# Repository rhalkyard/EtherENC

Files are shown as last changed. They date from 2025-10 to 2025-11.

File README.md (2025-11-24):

# ENC624J600-based Ethernet card for Acorn Archimedes and Risc PC systems

From the same person who still hasn't quite finished
[SEthernet](https://github.com/rhalkyard/SEthernet), comes yet another Ethernet
card for vintage computers!

Ethernet cards for Acorn systems are even harder to find than for vintage Macs.
This project is an attempt to bring a modern, low-cost Ethernet card to Acorn
Archimedes and Risc PC machines.

## Project Status

Early days yet! I have the driver functioning on a prototype version of the
card, but there are enough issues that it'll need a redone board before I'm
truly happy with it.

Meanwhile, someone else in the Acorn community who has access to a lot more
hardware for testing, has [announced his own open-source Ethernet
podule](https://www.stardot.org.uk/forums/viewtopic.php?p=468283). To be
brutally honest, his design is probably the sensible path forward, and there
probably isn't room for two very similar projects in such a small community, so
this project's future is in question. However, I'm proud of what I accomplished,
my design works well (in my opinion), and I think it's worth saving for
posterity, so here it is.

## Supported Systems

The intent is for this card to be compatible with any RISC OS machine with 16-
or 8-bit Podule slots, running RISC OS 3.10 or later. However, I only have
access to an A3000, so testing on later OSes and other machines will be up to
others!

## Hardware

See [HARDWARE.md](HARDWARE.md) for a design overview.

Schematic in PDF format can be found at
[pcb/EtherENC-prototype/EtherENC-Prototype.pdf](pcb/EtherENC-prototype/EtherENC-Prototype.pdf).

## Software

The [EtherENC/](EtherENC) directory contains driver source, buildable with Acorn
C/C++ version 5, which can be obtained from
[https://www.4corn.co.uk/articles/acornc5/](https://www.4corn.co.uk/articles/acornc5/),
or included in [RPCEMU](https://www.marutan.net/rpcemu/index.php)'s RISC OS 3.71
Easy-Start bundle.

If you are not used to RISC OS, the filenames and layout will look a little
weird. Instead of having extensions, `.c` and `.h` files live in separate
directories, and the comma-suffixes on various file names encode RISC OS file
types. Of particular interest, the `,ffb` files are BBC Basic programs, however
these are stored in a binary format and their source is not easily viewable on
non-RISC OS systems. Accompanying text dumps of the program code are included
alongside, I will endeavour to keep these up to date.

`MkROM` is a BASIC program that builds the card's ROM image with the appropriate
headers and loadable driver module.

`WriteROM` can then be used to program or update the card's flash with the new
ROM image.

### Checkout

Note that this repository includes the [RISC OS Open TCPIPLibs
source](https://gitlab.riscosopen.org/RiscOS/Sources/Lib/TCPIPLibs) as a
submodule. Specifically, it uses the
[TCPIPLibs-5_01](https://gitlab.riscosopen.org/RiscOS/Sources/Lib/TCPIPLibs/-/tree/TCPIPLibs-5_01)
tag, as this corresponds to the DCI 4.04 specification, without bringing in a
bunch of changes that make old versions of Acorn C/C++ get confused.

After cloning this repo, run `git submodule update --init` to set up submodules
correctly.

### Building

1. Install Acorn C/C++ and run `!SetPaths` inside the Acorn C/C++ directory.

2. Run the `!Mk` script in the source directory (or run `amu` from a TaskWindow
   or CLI).

### Flashing

1. After building the EtherENC driver, run `WriteROM` and follow the prompts.

### Installation

These instructions assume that you are using the version of `!Internet` included
in the Universal !Boot distribution. If you are using something else, you should
probably be able to figure out how to adapt them to your setup!

1. Copy `AutoSense.EtherENC` to
   `!Boot.Resources.Configure.!InetSetup.AutoSense`.

2. (optional) Copy the built `EtherENC` module to
   `!Boot.Resources.System.Modules.Network`. The driver module from the card ROM
   should be sufficient, but when testing it can be useful to softload the
   module instead.

3. Restart RISC OS.

### Configuring

Configuring the card is more or less the same as any other network interface on
RISC OS, and is done by the `!Boot.Resources.Configure.!InetSetup` application:

1. Run `!Boot.Resources.Configure.!InetSetup`, and click the `Internet` icon.

2. Under `Interfaces`, tick the box next to `EtherENC`, click the adjacent
   `Configure...` button, and set your IP address and netmask. Unless you know
   what you're doing, `Obtain IP address` should be set to `Manually`, and
   `Primary interface` should be ticked.

2. Under `Routing`, enter your default gateway. Unless you know what you're
   doing, `Act as an IP router` and `Run RouteD` should not be ticked.

3. Under `Host names`, ether your hostname domain, and DNS server(s). Ensure
   that `Use name servers also` is selected.

4. Configure AUN and Access if necessary (doing so is beyond the scope of this
   document).

#### CMOS Settings

The system's CMOS memory is used to store hardware configuration options across
reboots. These options can be set and read using RISC OS' `*Configure` and
`*Status` commands.

`*Configure EENCFlow <unit> Off|On` - Enable or disable PAUSE-frame flow
control, which may help mitigate packet drops on heavily-loaded systems. Default
is `Off`. Flow control can only operate on full-duplex links.

`*Configure EENCLink <unit> Auto | 10 Half|Full | 100 Half|Full` - Configure
link mode. `Auto` (the default) causes link speed and duplex mode to be
autonegotiated with the link partner. Otherwise, a fixed speed and duplex
setting (one of `10 Half`, `10 Full`, `100 Half` or `100 Full`) can be set.

After installing the card, or moving it into another slot, it may be necessary
to reconfigure the card in order to overwrite any leftover CMOS settings from
previous residents of that slot. Defaults can be restored with:

```
*Configure EENCLink <unit> Auto
*Configure EENCFlow <unit> Off
```

## Licenses

Hardware (everything in the `pcb` and `pld` directories) is licensed under the
CERN Open Hardware License Version 2 - Strongly Reciprocal.

The driver (everything in the `EtherENC` directory) is licensed under the GNU
Public License Version 3, with the following exceptions:

- `EtherENC.s.iocopy` contains code derived from the 
  ["Ether1" driver](https://gitlab.riscosopen.org/RiscOS/Sources/Networking/Ethernet/Ether1/) 
  as published by Risc OS Online Ltd., under the Apache License, version 2.0.

- `EtherENC.h.filter` and `EtherENC.c.filter` contain code derived from the
  ["EtherY" driver](https://gitlab.riscosopen.org/RiscOS/Sources/Networking/Ethernet/EtherY/)
  as published by RISC OS Online Ltd., under the BSD License.

- `EtherENC.h.syslog` and `EtherENC.s.syslog` are included unmodified from the
  SysLog freeware application (https://compton.nu/software/riscos/syslog).

## To Do

- Finalise hardware design

- Performance testing and driver optimisation

## Allocations

Names and IDs registered with ROOL (see
[https://www.riscosopen.org/content/allocate](https://www.riscosopen.org/content/allocate)
for info). If you fork EtherENC and make software-incompatible changes, please
request your own allocations, as these are registered to me personally. However,
if your EtherENC-derived hardware is fully compatible with the mainline EtherENC
driver, you are welcome to use the same Podule IDs.

| Allocation Type | Allocation | Source locations |
| --- | --- | --- |
| Ethernet Driver Suffix | `ENC` | Everywhere |
| SWI Base | &5A9C0 | [`cmhg.ModuleHdr`](cmhg/ModuleHdr) |
| Module Name | `EtherENC` | [`cmhg.ModuleHdr`](cmhg/ModuleHdr) |
| Commands | `EENCInfo`, `EENCTest`, `EENCFlow`, `EENCLink` | [`cmhg.ModuleHdr`](cmhg/ModuleHdr), [`c.module`](c/module) |
| Error Block | &822800 | [`h.errors`](h/errors), [`MkROM`](MkROM.bas) |
| Podule Manufacturer ID | &72 | [`h.if_enc`](h/if_enc), [`MkROM`](MkROM.bas) |
| Podule Type ID | &14E (16 bit), &14F (8 bit) | [`h.if_enc`](h/if_enc), [`MkROM`](MkROM.bas) |

## References

- [RISC OS 3 Programmer's Reference Manual](http://www.riscos.com/support/developers/prm/)

- [Acorn Enhanced Expansion Card
  Specification](https://www.chiark.greenend.org.uk/~theom/riscos/docs/expspec.pdf)

- [RISC OS DCI4 Reference Manuals](https://gerph.github.io/riscos-prm-dci4/)

- [Ether1 (AMD LANCE-based card) driver source](https://gitlab.riscosopen.org/RiscOS/Sources/Networking/Ethernet/Ether1)

- [EtherY (LAN91C111-based card) driver source](https://gitlab.riscosopen.org/RiscOS/Sources/Networking/Ethernet/EtherY/)

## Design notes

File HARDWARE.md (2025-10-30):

# EtherENC Hardware

The hardware design has not been finalised (though a working prototype exists).
The basic schematic has been laid out, but board designs are still a work in
progress. Hopefully this document and the schematic will aid in understanding
the method to my madness.

## Key Components

Ethernet Controller: [Microchip
ENC624J600](https://ww1.microchip.com/downloads/en/devicedoc/39935b.pdf)

Flash ROM: [Microchip
SST39SF010](https://ww1.microchip.com/downloads/en/DeviceDoc/20005022C.pdf)

Glue logic CPLD: [Atmel
ATF1502](https://ww1.microchip.com/downloads/en/DeviceDoc/Atmel-0995-CPLD-ATF1502AS(L)-Datasheet.pdf)

## DIY-ability

A major intent of this project is to be low-cost and DIY-assemblable by the
skilled amateur, without any expensive tools or exotic skills. This is
constrained somewhat by the fact that the ENC624J600 and ATF1502 are only
available in surface-mount packages, but nevertheless they can still be
hand-soldered with good-quality flux, desoldering braid, and some practice.

Since surface-mount components were going to be involved anyway, I have gone
ahead and made everything surface mount, but avoided any unreasonably-tiny
footprints - the passives are all 0603 or larger. The trickiest part is the
ENC624J600 (a TQFP-44 with 0.5mm pin pitch), but there is no easier alternative.

Programming the ATF1502 requires a JTAG interface of some sort, however these
can be had very cheaply, and most can be driven by the free OpenOCD suite. Once
the ATF1502 is programmed, the flash ROM can be programmed in-system from RISC
OS, and this repo includes a simple BASIC program to do this.

## Data Width

The basic hardware design is intended to support both 16-bit standard Podules,
and the 8-bit 'mini Podules' used in the A3000, A4000 and A3010, with only minor
changes (configuration strapping of the ENC624J600, and paging of the buffer
RAM). Software handling of the two cards will differ, and 8 bit support has not
been implemented or tested yet, but much of the driver logic should be
applicable to both.

## Memory Map

| Mode | Address range | Read/Write | Width | Description |
| --- | --- | --- | --- | --- |
| IOC Fast | `0000-1FFF` | R/W <sup>1</sup> | 8 | Paged access to flash ROM <sup>2</sup> |
| IOC Fast | `2000` (shadowed through `23FF`) | R | 8 | IRQ status register |
| IOC Fast | `2000` (shadowed through `23FF`) | W | 8 | Paging latch for ROM and buffer RAM |
| IOC Fast | `2400-37FF` | - | - | Unused <sup>3</sup> |
| IOC Fast | `3800-3FFF` | R/W | 8/16 <sup>4</sup> | ENC624J600 registers <sup>5</sup> |
| MEMC | `0000-3FFF` | R/W | 8/16 <sup>4</sup> | Paged access to ENC624J600 address space <sup>6</sup> |

**Note 1:** Flash ROM is not directly writeable, but can be erased and
re-written with 'magic' write sequences. See `WriteROM`'s BASIC source for an
example implementation.

**Note 2:** 64 pages of 2048 bytes for 16 bit cards, 32 pages for 8 bit cards.

**Note 3:** Unused space is intended to accommodate the future inclusion of an
IanS-style IDE interface.

**Note 4:** Configurable by strapping pins.

**Note 5:** 256 16-bit registers for 16 bit cards, or 512 8-bit registers for
8-bit cards.

**Note 6:** 4 pages of 4096 halfwords for 16-bit cards, or 4 pages of 4096 bytes
for 8-bit cards (covering only top half of ENC624J600 address space in 8-bit mode).

### IRQ Status Register

The ENC624J600 puts its main IRQ status bit in bit 15 of its status register. On
16-bit cards, this renders it inaccessible to RISC OS' Podule IRQ routines, as
they use `LDRB` to read the status register, and Podules do not allow arbitrary
byte access.

To work around this, an IRQ status register is implemented at address `0x2000`:

| Bit | Description |
| --- | --- |
| 0 | Card is asserting `/PIRQ` |
| 1-7 | Unimplemented, reserved |

### Paging Latch

Paging for both ROM and the ENC624J600's address space is controlled by a
write-only latch at `0x2000`. Paging of the ENC624J600 address space is
controlled through the `Podule_CallLoader` SWI so as to allow these two paging
functions to coexist in a single register.

Paging bits are mapped as follows:

| Bit | ROM | ENC624J600 <sup>1</sup> |
| --- | --- | --- |
| 0 | A11 | - |
| 1 | A12 | - |
| 2 | A13 | - |
| 3 | A14 | - |
| 4 | A15 | - |
| 5 | A16 | - |
| 6 | - | A12 |
| 7 | - | A13 |

**Note 1:** In 16-bit mode, the ENC624J600's address pins correspond to halfword
addresses, rather than byte addresses.

Note that for 8-bit cards, there are insufficient paging bits to access the
entirety of the ENC624J600's memory. Address line A14 (unused in 16 bit mode) is
tied high, restricting paged access to the top 16K of the ENC624J600's address
space. This effectively prevents direct paged access to buffer memory, requiring
use of the ENC624J600's indirection registers instead.

## Theory of Operation

The ENC624J600 has a 32KB address space, providing 24KB of onboard buffer SRAM,
and a register bank at the top of its address space. In 16-bit mode, this
address space is laid out as 16K 16-bit halfwords. In 8-bit mode, an additional
address line is used, and access is as 32K 8-bit bytes. Due to the limitaitons
of the Podule bus, individual byte addressing in 16-bit mode is *not* possible. 

A commodity RJ45 jack with integrated magnetics and LEDs is used to simplify the
design. ROM is provided by an SST39SF010 128kx8 flash memory, which can be
programmed in-system using an included BASIC utility. Control and timing logic
is all implemented within an ATF1502 CPLD. An 8-bit latch provides a write-only
paging register, controlling paging of both ROM and the ENC624J600's address
space.

The ENC624J600 can be addressed in two 'modes', goverened by an address buffer
under control of the ATF1502. When `ETH_/PAGE` is asserted, the full complement
of Podule address bits (`LA13`..`LA2`), plus two paging-latch bits
(`ETH_PG1`..`ETH_PG0`) cover the full address space of the ENC624J600 in 16 bit
mode <sup>1</sup>. This is used for MEMC mode accesses to the ENC624J600's
buffer RAM. When `ETH_/PAGE` is not asserted, the high bits of the ENC624J600's
address bus are undriven and pulled high, exposing only the register space. This
mode is used to expose just the ENC624J600's registers in IOC space at
`3800-38FF`.

The ENC624J600 is a 3.3V device, with 5V-tolerant I/O. Its 3.3V supply is
provided by an onboard LDO regulator. In future hardware revisions, a regulator
with an Enable input under control of the ATF1502. This will be used to work
around the ENC624J600's lack of a hardware reset pin, by power-on-resetting the
chip when the Podule `/RST` line is asserted.

All components are tolerant of 500ns 'fast' accesses (and all slower access
modes too). 250ns timing is used for MEMC-space accesses to the ENC624J600,
equivalent to a RAM 'N-cycle'. `LDM`/`STM` to ENC624J600 RAM through MEMC space
is supported, though timing remains at 250ns throughout, MEMC does not appear to
support S-cycles to I/O devices.

**Note 1:** On 8-bit cards, only the upper 16K of the ENC624J600's address space
is accessible in paged mode.

## Loader SWI interface

Due to the shared write-only nature of the paging register, access must be
coordinated through the loader interface to avoid disruption. Access to ROM must
go through standard RISC OS SWIs (`Podule_ReadBytes`, `Podule_ReadChunk` etc.),
and paging of the ENC624J600 address space must be controlled through the
`Podule_CallLoader` SWI as described below. This has the beneficial side effect
of providing an abstraciton layer over the different paging-bit assignments of
8- and 16-bit cards.

To accommodate changes in future hardware revisions, `Podule_CallLoader` is also
used to control power and interrupt-gating functions:

| R0 (reason code) | Function | R1 (argument) |
| --- | --- | --- |
| 0 | Set ENC624J600 page | Page number |
| 1 | Power-on ENC624J600 (currently a no-op) | Unused |
| 2 | Un-gate ENC624J600 IRQs | Unused |

## Power Control and Interrupt Gating

The ENC624J600 has no hardware reset pin - it can be reset only by power-cycling
it, or writing to a control register. The driver resets the ENC624J600 at module
exit, and does the same if it receives a `PreReset` service call, but if the
machine crashes or is reset abruptly, the ENC624J600 will be left in a
potentially interrupt-generating state.

The current hardware mitigates this by gating interrupts until the driver
indicates that it is in control, via the SWI interface described above. Future
revisions will additionally control the power to the ENC624J600, allowing it to
be fully reset through a power-cycle when the system is reset.

The driver must initialise the chip as follows (based on section 8.1 of the
ENC624J600 data sheet):

1. Call the `Podule_CallLoader` SWI for the appropriate slot, with R0 = 1.

2. Wait 25 microseconds for the ENC624J600 to come out of power-on reset.

3. Write `0x1234` to the EUDAST register and read it back, repeating until it
   reads back correctly.

4. Wait for the CLKRDY bit of the ESTAT register to be set.

5. Set the ETHRST bit of the ECON2 register.

6. Wait 25 microseconds for the ENC624J600 to come out of soft-reset.

7. Read the EUDAST register and ensure it has reset to `0x0000`.

8. Call the `Podule_CallLoader` SWI for the appropriate slot, with R0 = 2.

9. Wait 256 microseconds for the PHY to finish initialising.

## IDE Interface

As mentioned above, the address range `2400-37FF` is decoded, but left unmapped.
The intention is for future versions of this card to use this space for an IDE
interface - this is particularly desirable for the 8-bit version of the card, as
it would allow single-slot machines such as the A4000 and A3010 to have both IDE
and ethernet.

This gap in the address range is designed to accomodate the register map of the
popular 'IanS' IDE interfaces (both 8- and 16-bit variants). While IDE drivers
such as ZIDEFS will need to be modified to recognise the podule ID of a combined
Ethernet/IDE card, they should otherwise be software-compatible.

## Mechanical design

One remaining item to be resolved, is the design of back-panel brackets for
full-size and mini-podules. Fabrication out of sheet-metal is probably
cost-prohibitive, but it should be possible to 3D-print acceptable substitutes,
using Acorn's drawings as a guide.

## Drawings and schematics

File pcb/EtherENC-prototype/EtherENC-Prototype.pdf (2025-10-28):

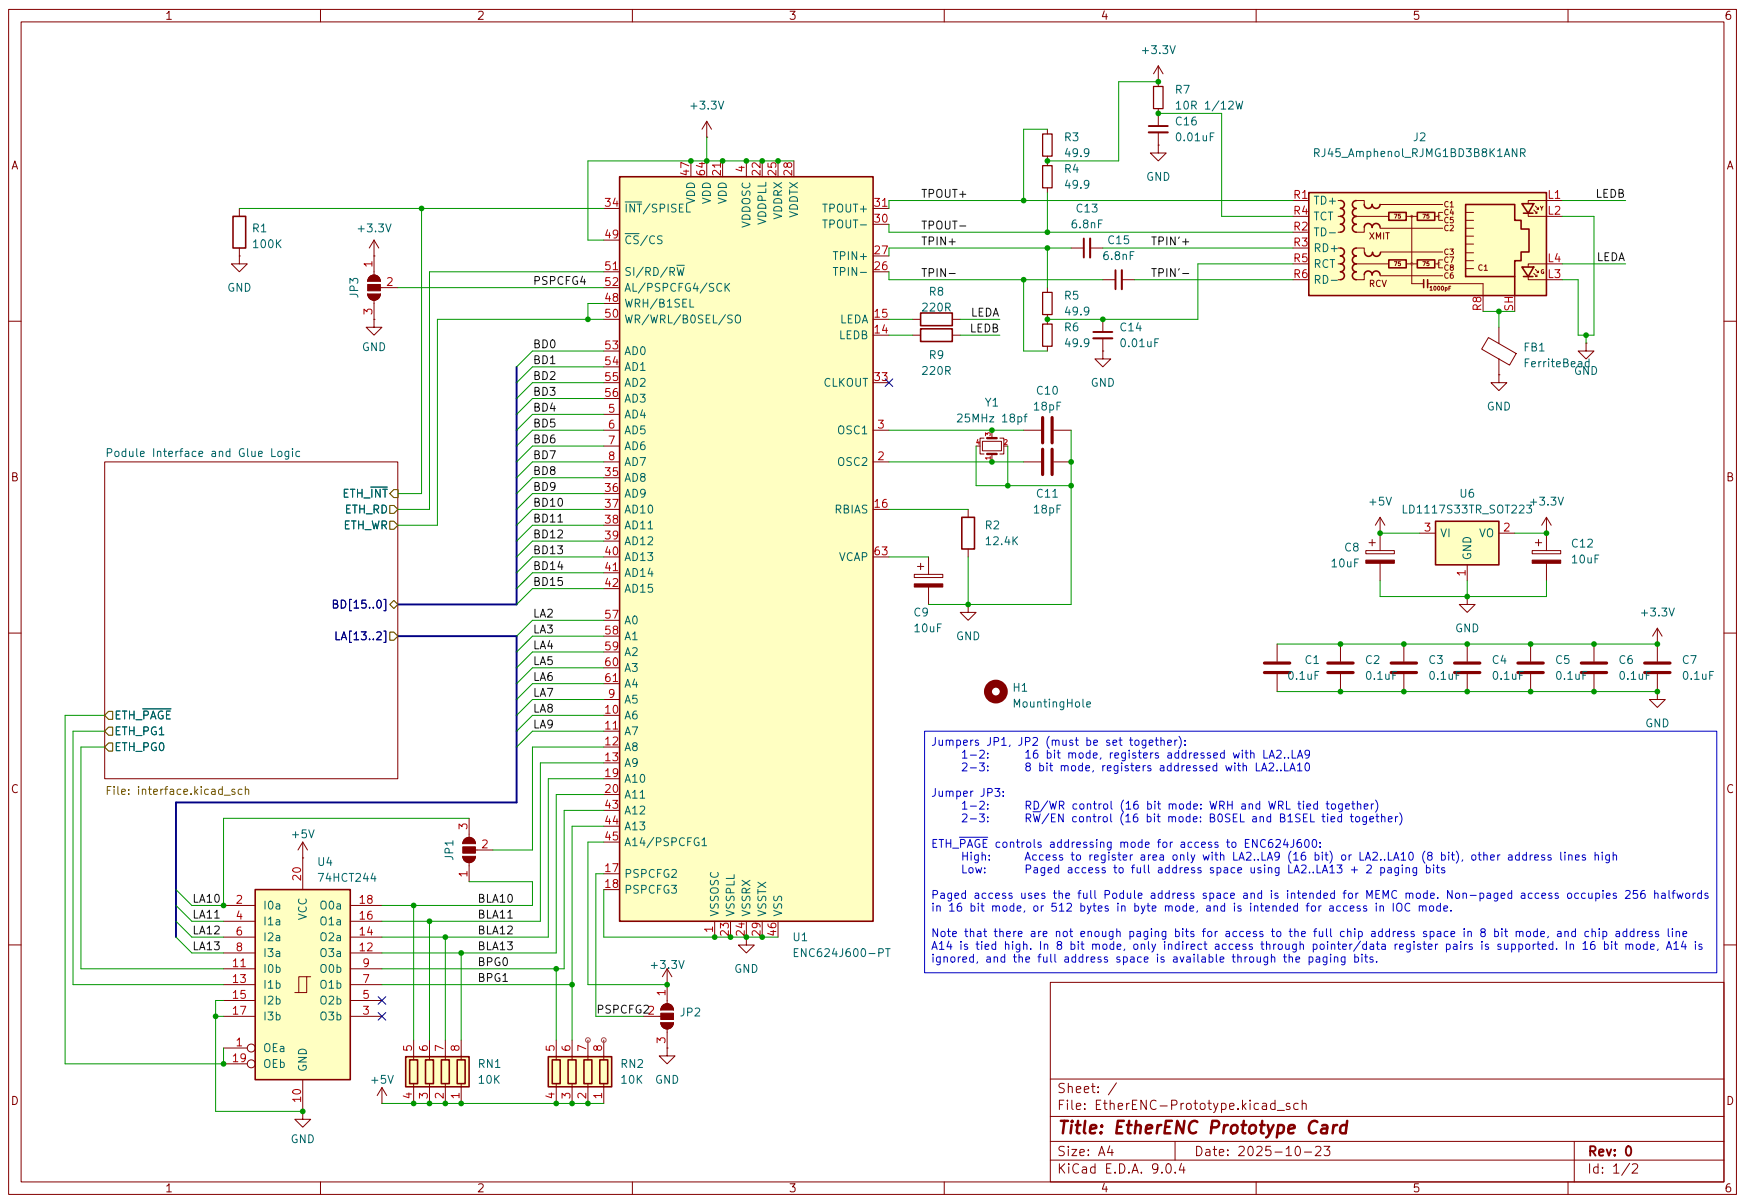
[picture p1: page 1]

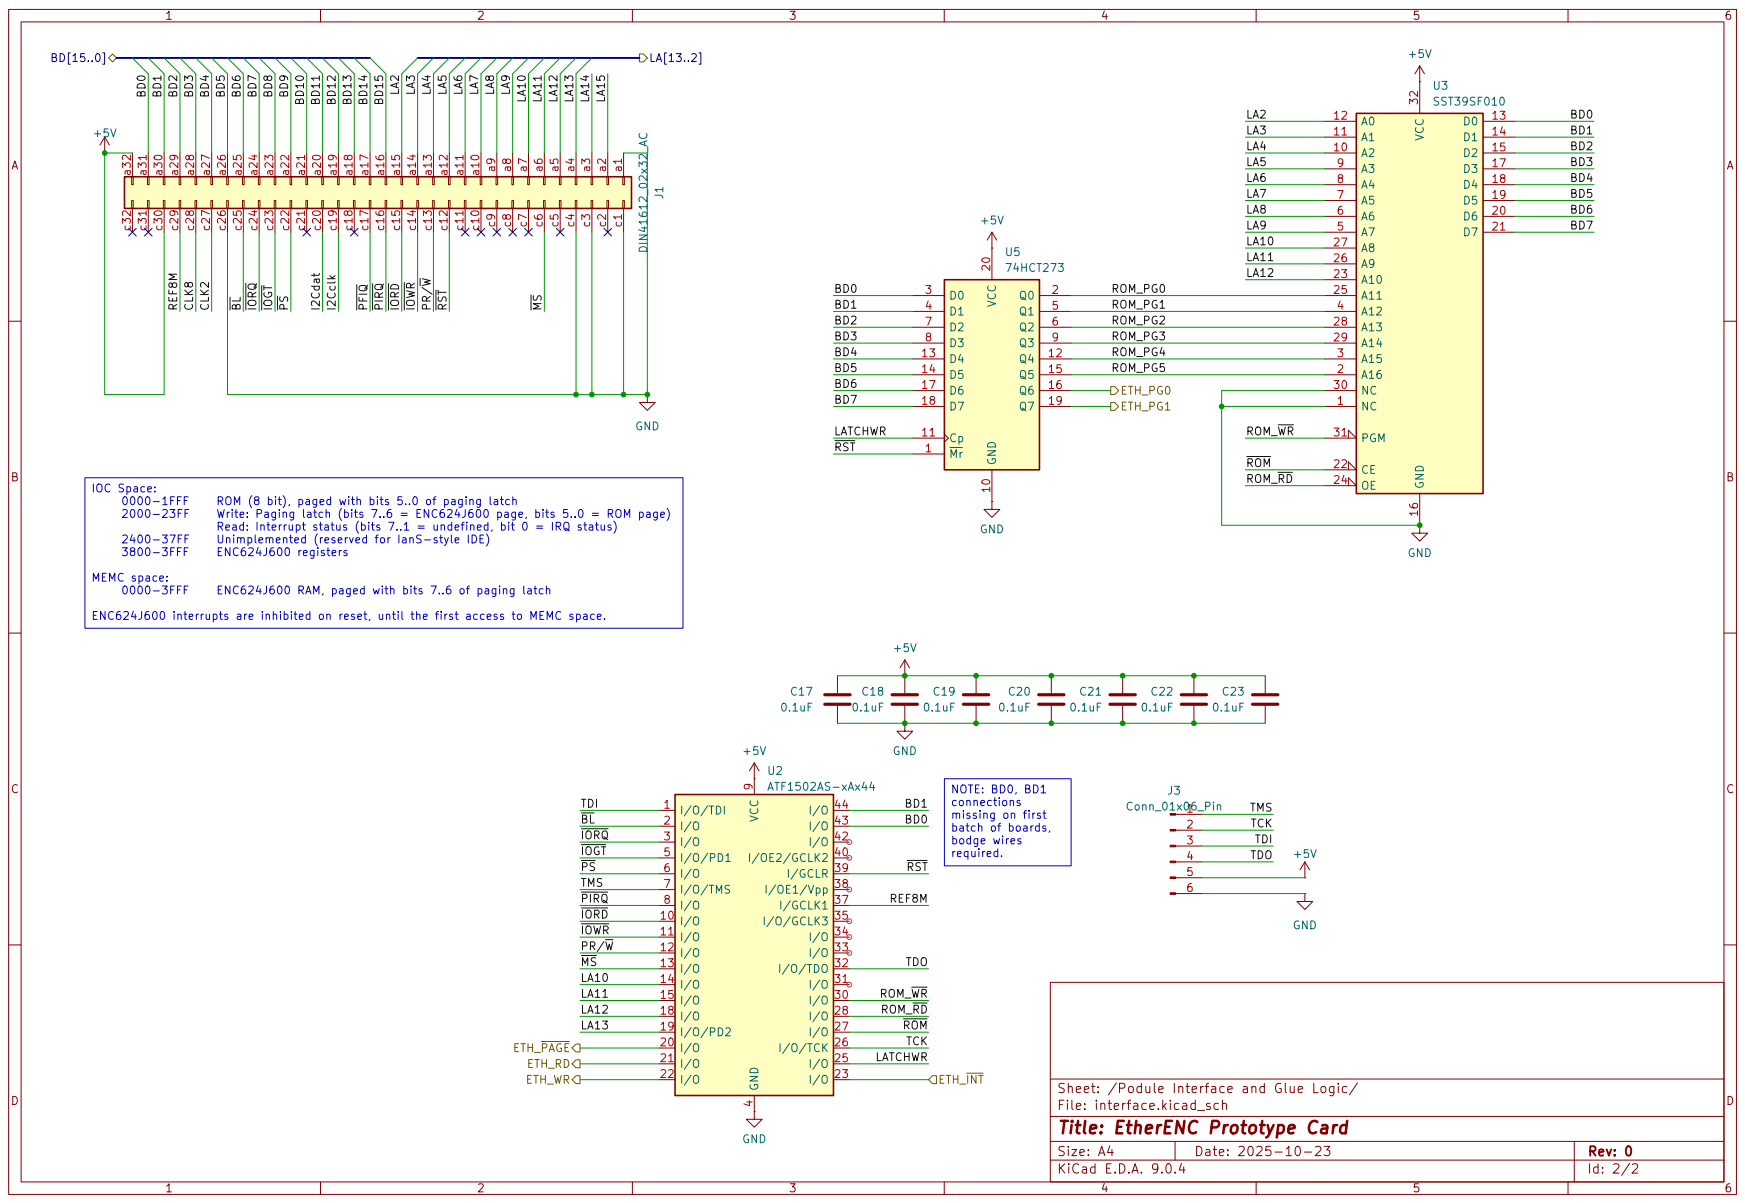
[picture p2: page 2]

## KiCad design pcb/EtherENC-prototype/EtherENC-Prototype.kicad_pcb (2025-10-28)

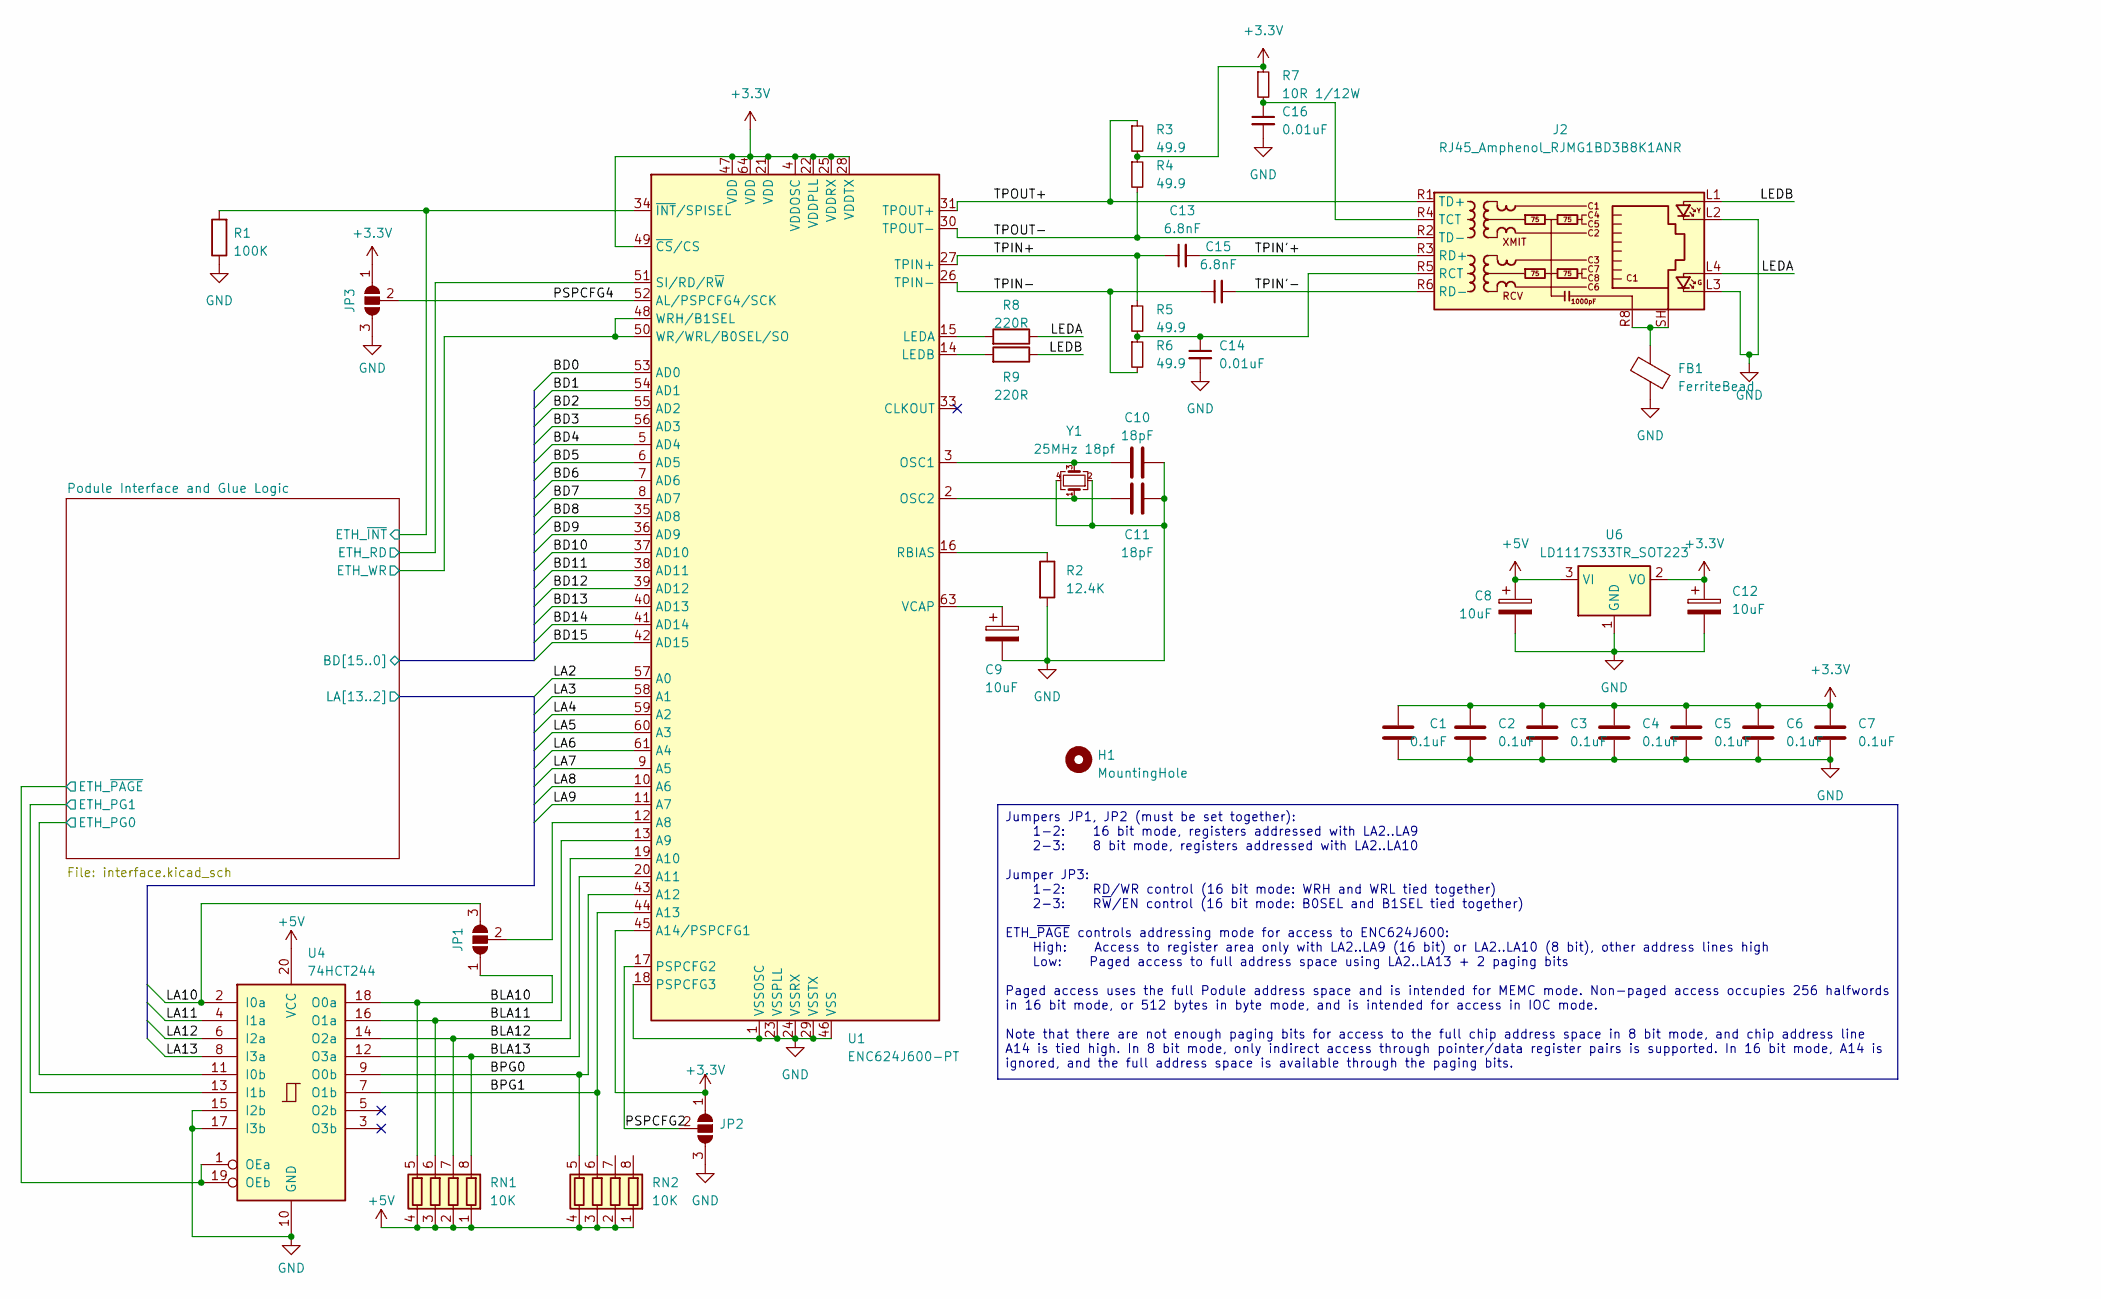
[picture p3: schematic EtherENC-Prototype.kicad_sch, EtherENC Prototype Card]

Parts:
C1, C2, C3, C4, C5, C6, C7: 0.1uF; C_0805_2012Metric_Pad1.18x1.45mm_HandSolder; Digikey 399-C0805C104M5RAC7800CT-ND
C8, C9, C12: 10uF; CP_EIA-3216-18_Kemet-A_Pad1.58x1.35mm_HandSolder; Digikey 718-1118-1-ND
C10, C11: 18pF; C_0805_2012Metric_Pad1.18x1.45mm_HandSolder; Digikey 399-C0805C180K5GAC7800CT-ND
C13, C15: 6.8nF; C_0805_2012Metric_Pad1.18x1.45mm_HandSolder; Digikey 399-C0805C682K5RAC7800CT-ND
C14, C16: 0.01uF; C_0805_2012Metric_Pad1.18x1.45mm_HandSolder; Digikey 399-C0805C103K5RACTUCT-ND
FB1: FerriteBead; L_0805_2012Metric_Pad1.15x1.40mm_HandSolder; Digikey 240-2549-1-ND
H1: MountingHole; MountingHole_3.2mm_M3
J2: RJ45_Amphenol_RJMG1BD3B8K1ANR; Digikey RJMG1BD3B8K1ANR-ND
JP1, JP2, JP3: SolderJumper_3_Open; SolderJumper-3_P1.3mm_Open_RoundedPad1.0x1.5mm
R1: 100K; R_0805_2012Metric_Pad1.20x1.40mm_HandSolder; Digikey RMCF0805FT100KCT-ND
R2: 12.4K; R_0805_2012Metric_Pad1.20x1.40mm_HandSolder; Digikey RMCF0805FT12K4CT-ND
R3, R4, R5, R6: 49.9; R_0805_2012Metric_Pad1.20x1.40mm_HandSolder; Digikey RMCF0805FT49R9CT-ND
R7: 10R 1/12W; R_0805_2012Metric_Pad1.20x1.40mm_HandSolder; Digikey RMCF0805FT10R0CT-ND
R8, R9: 220R; R_0805_2012Metric_Pad1.20x1.40mm_HandSolder; Digikey RMCF0805FT221RCT-ND
RN1, RN2: 10K; R_Array_Concave_4x0603; Digikey CAT16-103J4LFCT-ND
U1: ENC624J600-PT; TQFP-64_10x10mm_P0.5mm; Digikey ENC624J600-I/PT-ND
U4: 74HCT244; TSSOP-20_4.4x6.5mm_P0.65mm; Digikey 296-8402-1-ND
U6: LD1117S33TR_SOT223; SOT-223-3_TabPin2; Digikey 497-1242-1-ND
Y1: 25MHz 18pf; Crystal_SMD_3225-4Pin_3.2x2.5mm_HandSoldering; Digikey 2151-RH100-25.000-18-F-1020-EXT-TRCT-ND

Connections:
+3.3V: C1.2, C2.1, C3.1, C4.2, C5.1, C6.2, C7.1, C12.1, JP2.1 (A), JP3.1 (A), R3.2, R4.1, R7.1, U1.4 (VDDOSC), U1.21 (VDD), U1.22 (VDDPLL), U1.25 (VDDRX), U1.28 (VDDTX), U1.45 (A14/PSPCFG1), U1.47 (VDD), U1.49 (~CS/CS), U1.64 (VDD), U6.2 (VO)
+5V: C8.1, RN1.1 (R1.1), RN1.2 (R2.1), RN1.3 (R3.1), RN1.4 (R4.1), RN2.1 (R1.1), RN2.2 (R2.1), RN2.3 (R3.1), RN2.4 (R4.1), U4.20 (VCC), U6.3 (VI); also elsewhere on the board
/BLA10: JP1.1 (A), RN1.5 (R4.2), U4.18 (O0a)
/BLA11: RN1.6 (R3.2), U1.13 (A9), U4.16 (O1a)
/BLA12: RN1.7 (R2.2), U1.19 (A10), U4.14 (O2a)
/BLA13: RN1.8 (R1.2), U1.20 (A11), U4.12 (O3a)
/BPG0: RN2.5 (R4.2), U1.43 (A12), U4.9 (O0b)
/BPG1: RN2.6 (R3.2), U1.44 (A13), U4.7 (O1b)
/LEDA: J2.L4, R8.1
/LEDB: J2.L1, R9.1
/PSPCFG2: JP2.2 (C), U1.17 (PSPCFG2)
/PSPCFG4: JP3.2 (C), U1.52 (AL/PSPCFG4/SCK)
/Podule Interface and Glue Logic/BD0: U1.53 (AD0); also elsewhere on the board
/Podule Interface and Glue Logic/BD1: U1.54 (AD1); also elsewhere on the board
/Podule Interface and Glue Logic/BD2: U1.55 (AD2); also elsewhere on the board
/Podule Interface and Glue Logic/BD3: U1.56 (AD3); also elsewhere on the board
/Podule Interface and Glue Logic/BD4: U1.5 (AD4); also elsewhere on the board
/Podule Interface and Glue Logic/BD5: U1.6 (AD5); also elsewhere on the board
/Podule Interface and Glue Logic/BD6: U1.7 (AD6); also elsewhere on the board
/Podule Interface and Glue Logic/BD7: U1.8 (AD7); also elsewhere on the board
/Podule Interface and Glue Logic/BD8: U1.35 (AD8); also elsewhere on the board
/Podule Interface and Glue Logic/BD9: U1.36 (AD9); also elsewhere on the board
/Podule Interface and Glue Logic/BD10: U1.37 (AD10); also elsewhere on the board
/Podule Interface and Glue Logic/BD11: U1.38 (AD11); also elsewhere on the board
/Podule Interface and Glue Logic/BD12: U1.39 (AD12); also elsewhere on the board
/Podule Interface and Glue Logic/BD13: U1.40 (AD13); also elsewhere on the board
/Podule Interface and Glue Logic/BD14: U1.41 (AD14); also elsewhere on the board
/Podule Interface and Glue Logic/BD15: U1.42 (AD15); also elsewhere on the board
/Podule Interface and Glue Logic/ETH_PG0: U4.11 (I0b); also elsewhere on the board
/Podule Interface and Glue Logic/ETH_PG1: U4.13 (I1b); also elsewhere on the board
/Podule Interface and Glue Logic/ETH_RD: U1.51 (SI/RD/R~W); also elsewhere on the board
/Podule Interface and Glue Logic/ETH_WR: U1.48 (WRH/B1SEL), U1.50 (WR/WRL/B0SEL/SO); also elsewhere on the board
/Podule Interface and Glue Logic/ETH_~INT: R1.2, U1.34 (~INT/SPISEL); also elsewhere on the board
/Podule Interface and Glue Logic/ETH_~PAGE: U4.1 (OEa), U4.19 (OEb); also elsewhere on the board
/Podule Interface and Glue Logic/LA2: U1.57 (A0); also elsewhere on the board
/Podule Interface and Glue Logic/LA3: U1.58 (A1); also elsewhere on the board
/Podule Interface and Glue Logic/LA4: U1.59 (A2); also elsewhere on the board
/Podule Interface and Glue Logic/LA5: U1.60 (A3); also elsewhere on the board
/Podule Interface and Glue Logic/LA6: U1.61 (A4); also elsewhere on the board
/Podule Interface and Glue Logic/LA7: U1.9 (A5); also elsewhere on the board
/Podule Interface and Glue Logic/LA8: U1.10 (A6); also elsewhere on the board
/Podule Interface and Glue Logic/LA9: U1.11 (A7); also elsewhere on the board
/Podule Interface and Glue Logic/LA10: JP1.3 (B), U4.2 (I0a); also elsewhere on the board
/Podule Interface and Glue Logic/LA11: U4.4 (I1a); also elsewhere on the board
/Podule Interface and Glue Logic/LA12: U4.6 (I2a); also elsewhere on the board
/Podule Interface and Glue Logic/LA13: U4.8 (I3a); also elsewhere on the board
/TPIN'+: C13.2, J2.R3 (RD+)
/TPIN'-: C15.2, J2.R6 (RD-)
/TPIN+: C13.1, R5.1, U1.27 (TPIN+)
/TPIN-: C15.1, R6.2, U1.26 (TPIN-)
/TPOUT+: J2.R1 (TD+), R3.1, U1.31 (TPOUT+)
/TPOUT-: J2.R2 (TD-), R4.2, U1.30 (TPOUT-)
GND: C1.1, C2.2, C3.2, C4.1, C5.2, C6.1, C7.2, C8.2, C9.2, C10.2, C11.2, C12.2, C14.2, C16.2, FB1.1, J2.L2, J2.L3, JP2.3 (B), JP3.3 (B), R1.1, R2.2, U1.1 (VSSOSC), U1.18 (PSPCFG3), U1.23 (VSSPLL), U1.24 (VSSRX), U1.29 (VSSTX), U1.32 (VSSTX), U1.46 (VSS), U1.62 (VSS), U4.10 (GND), U4.15 (I2b), U4.17 (I3b), U6.1 (GND), Y1.2, Y1.4; also elsewhere on the board
unnamed: FB1.2, J2.R8, J2.SH
unnamed: C14.1, J2.R5 (RCT), R5.2, R6.1
unnamed: C16.1, J2.R4 (TCT), R7.2
unnamed: JP1.2 (C), U1.12 (A8)
unnamed: R8.2, U1.15 (LEDA)
unnamed: R9.2, U1.14 (LEDB)
unnamed: C10.1, U1.3 (OSC1), Y1.3
unnamed: C11.1, U1.2 (OSC2), Y1.1
unnamed: R2.1, U1.16 (RBIAS)
unnamed: C9.1, U1.63 (VCAP)

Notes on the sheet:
Jumpers JP1, JP2 (must be set together): 1-2: 16 bit mode, registers addressed with LA2..LA9 2-3: 8 bit mode, registers addressed with LA2..LA10 Jumper JP3: 1-2: RD/WR control (16 bit mode: WRH and WRL tied together) 2-3: R~{W}/EN control (16 bit mode: B0SEL and B1SEL tied together) ETH_~{PAGE} con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

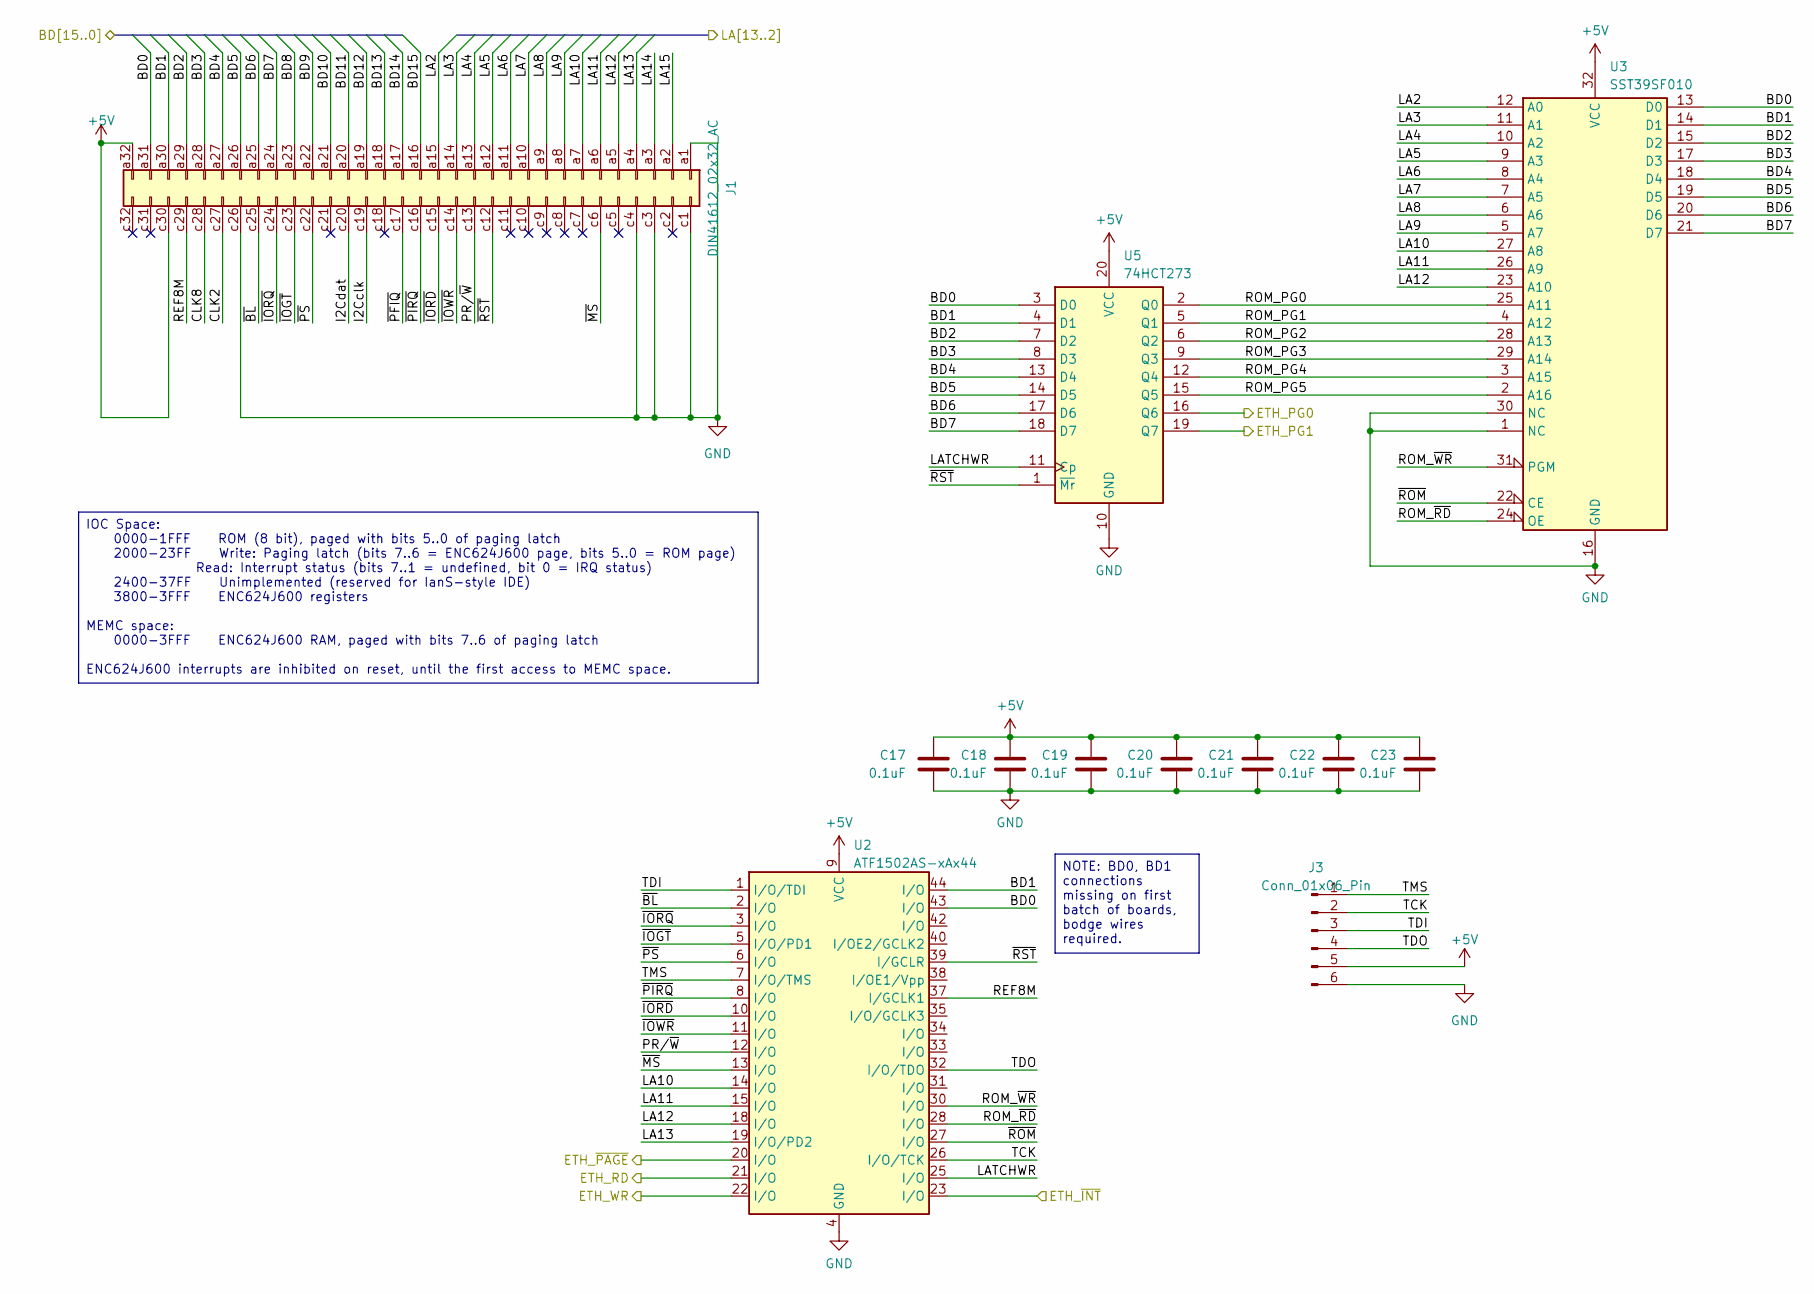
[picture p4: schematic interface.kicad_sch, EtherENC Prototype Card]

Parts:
C17, C18, C19, C20, C21, C22, C23: 0.1uF; C_0805_2012Metric_Pad1.18x1.45mm_HandSolder; Digikey 399-C0805C104M5RAC7800CT-ND
J1: DIN41612_02x32_AC; DIN41612_C_3x32_Male_Horizontal_THT
J3: Conn_01x06_Pin; PinHeader_1x06_P2.54mm_Vertical
U2: ATF1502AS-xAx44; TQFP-44_10x10mm_P0.8mm; Digikey ATF1502AS-10AU44-ND
U3: SST39SF010; PLCC-32_THT-Socket; Digikey SST39SF010A-70-4C-NHE-ND
U5: 74HCT273; TSSOP-20_4.4x6.5mm_P0.65mm; Digikey 296-8409-1-ND

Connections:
+5V: C17.2, C18.2, C19.2, C20.2, C21.2, C22.2, C23.2, J1.a32, J1.c30, J3.5, U2.9 (VCC), U2.17 (VCC), U2.29 (VCC), U2.41 (VCC), U3.32 (VCC), U5.20 (VCC); also elsewhere on the board
/Podule Interface and Glue Logic/BD0: J1.a31, U2.43 (I/O), U3.13 (D0), U5.3 (D0); also elsewhere on the board
/Podule Interface and Glue Logic/BD1: J1.a30, U2.44 (I/O), U3.14 (D1), U5.4 (D1); also elsewhere on the board
/Podule Interface and Glue Logic/BD2: J1.a29, U3.15 (D2), U5.7 (D2); also elsewhere on the board
/Podule Interface and Glue Logic/BD3: J1.a28, U3.17 (D3), U5.8 (D3); also elsewhere on the board
/Podule Interface and Glue Logic/BD4: J1.a27, U3.18 (D4), U5.13 (D4); also elsewhere on the board
/Podule Interface and Glue Logic/BD5: J1.a26, U3.19 (D5), U5.14 (D5); also elsewhere on the board
/Podule Interface and Glue Logic/BD6: J1.a25, U3.20 (D6), U5.17 (D6); also elsewhere on the board
/Podule Interface and Glue Logic/BD7: J1.a24, U3.21 (D7), U5.18 (D7); also elsewhere on the board
/Podule Interface and Glue Logic/BD8: J1.a23; also elsewhere on the board
/Podule Interface and Glue Logic/BD9: J1.a22; also elsewhere on the board
/Podule Interface and Glue Logic/BD10: J1.a21; also elsewhere on the board
/Podule Interface and Glue Logic/BD11: J1.a20; also elsewhere on the board
/Podule Interface and Glue Logic/BD12: J1.a19; also elsewhere on the board
/Podule Interface and Glue Logic/BD13: J1.a18; also elsewhere on the board
/Podule Interface and Glue Logic/BD14: J1.a17; also elsewhere on the board
/Podule Interface and Glue Logic/BD15: J1.a16; also elsewhere on the board
/Podule Interface and Glue Logic/CLK2: J1.c27
/Podule Interface and Glue Logic/CLK8: J1.c28
/Podule Interface and Glue Logic/ETH_PG0: U5.16 (Q6); also elsewhere on the board
/Podule Interface and Glue Logic/ETH_PG1: U5.19 (Q7); also elsewhere on the board
/Podule Interface and Glue Logic/ETH_RD: U2.21 (I/O); also elsewhere on the board
/Podule Interface and Glue Logic/ETH_WR: U2.22 (I/O); also elsewhere on the board
/Podule Interface and Glue Logic/ETH_~INT: U2.23 (I/O); also elsewhere on the board
/Podule Interface and Glue Logic/ETH_~PAGE: U2.20 (I/O); also elsewhere on the board
/Podule Interface and Glue Logic/I2Cclk: J1.c19
/Podule Interface and Glue Logic/I2Cdat: J1.c20
/Podule Interface and Glue Logic/LA2: J1.a15, U3.12 (A0); also elsewhere on the board
/Podule Interface and Glue Logic/LA3: J1.a14, U3.11 (A1); also elsewhere on the board
/Podule Interface and Glue Logic/LA4: J1.a13, U3.10 (A2); also elsewhere on the board
/Podule Interface and Glue Logic/LA5: J1.a12, U3.9 (A3); also elsewhere on the board
/Podule Interface and Glue Logic/LA6: J1.a11, U3.8 (A4); also elsewhere on the board
/Podule Interface and Glue Logic/LA7: J1.a10, U3.7 (A5); also elsewhere on the board
/Podule Interface and Glue Logic/LA8: J1.a9, U3.6 (A6); also elsewhere on the board
/Podule Interface and Glue Logic/LA9: J1.a8, U3.5 (A7); also elsewhere on the board
/Podule Interface and Glue Logic/LA10: J1.a7, U2.14 (I/O), U3.27 (A8); also elsewhere on the board
/Podule Interface and Glue Logic/LA11: J1.a6, U2.15 (I/O), U3.26 (A9); also elsewhere on the board
/Podule Interface and Glue Logic/LA12: J1.a5, U2.18 (I/O), U3.23 (A10); also elsewhere on the board
/Podule Interface and Glue Logic/LA13: J1.a4, U2.19 (I/O/PD2); also elsewhere on the board
/Podule Interface and Glue Logic/LA14: J1.a3
/Podule Interface and Glue Logic/LA15: J1.a2
/Podule Interface and Glue Logic/LATCHWR: U2.25 (I/O), U5.11 (Cp)
/Podule Interface and Glue Logic/PR/~W: J1.c13, U2.12 (I/O)
/Podule Interface and Glue Logic/REF8M: J1.c29, U2.37 (I/GCLK1)
/Podule Interface and Glue Logic/ROM_PG0: U3.25 (A11), U5.2 (Q0)
/Podule Interface and Glue Logic/ROM_PG1: U3.4 (A12), U5.5 (Q1)
/Podule Interface and Glue Logic/ROM_PG2: U3.28 (A13), U5.6 (Q2)
/Podule Interface and Glue Logic/ROM_PG3: U3.29 (A14), U5.9 (Q3)
/Podule Interface and Glue Logic/ROM_PG4: U3.3 (A15), U5.12 (Q4)
/Podule Interface and Glue Logic/ROM_PG5: U3.2 (A16), U5.15 (Q5)
/Podule Interface and Glue Logic/ROM_~RD: U2.28 (I/O), U3.24 (OE)
/Podule Interface and Glue Logic/ROM_~WR: U2.30 (I/O), U3.31 (PGM)
/Podule Interface and Glue Logic/TCK: J3.2, U2.26 (I/O/TCK)
/Podule Interface and Glue Logic/TDI: J3.3, U2.1 (I/O/TDI)
/Podule Interface and Glue Logic/TDO: J3.4, U2.32 (I/O/TDO)
/Podule Interface and Glue Logic/TMS: J3.1, U2.7 (I/O/TMS)
/Podule Interface and Glue Logic/~BL: J1.c25, U2.2 (I/O)
/Podule Interface and Glue Logic/~IOGT: J1.c23, U2.5 (I/O/PD1)
/Podule Interface and Glue Logic/~IORD: J1.c15, U2.10 (I/O)
/Podule Interface and Glue Logic/~IORQ: J1.c24, U2.3 (I/O)
/Podule Interface and Glue Logic/~IOWR: J1.c14, U2.11 (I/O)
/Podule Interface and Glue Logic/~MS: J1.c6, U2.13 (I/O)
/Podule Interface and Glue Logic/~PFIQ: J1.c17
/Podule Interface and Glue Logic/~PIRQ: J1.c16, U2.8 (I/O)
/Podule Interface and Glue Logic/~PS: J1.c22, U2.6 (I/O)
/Podule Interface and Glue Logic/~ROM: U2.27 (I/O), U3.22 (CE)
/Podule Interface and Glue Logic/~RST: J1.c12, U2.39 (I/GCLR), U5.1 (~Mr)
GND: C17.1, C18.1, C19.1, C20.1, C21.1, C22.1, C23.1, J1.a1, J1.c1, J1.c3, J1.c4, J1.c26, J3.6, U2.4 (GND), U2.16 (GND), U2.24 (GND), U2.36 (GND), U3.1 (NC), U3.16 (GND), U3.30 (NC), U5.10 (GND); also elsewhere on the board

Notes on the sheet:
NOTE: BD0, BD1 connections missing on first batch of boards, bodge wires required.
IOC Space: 0000-1FFF ROM (8 bit), paged with bits 5..0 of paging latch 2000-23FF Write: Paging latch (bits 7..6 = ENC624J600 page, bits 5..0 = ROM page) Read: Interrupt status (bits 7..1 = undefined, bit 0 = IRQ status) 2400-37FF Unimplemented (reserved for IanS-style IDE) 3800-3FFF ENC624J600 regi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

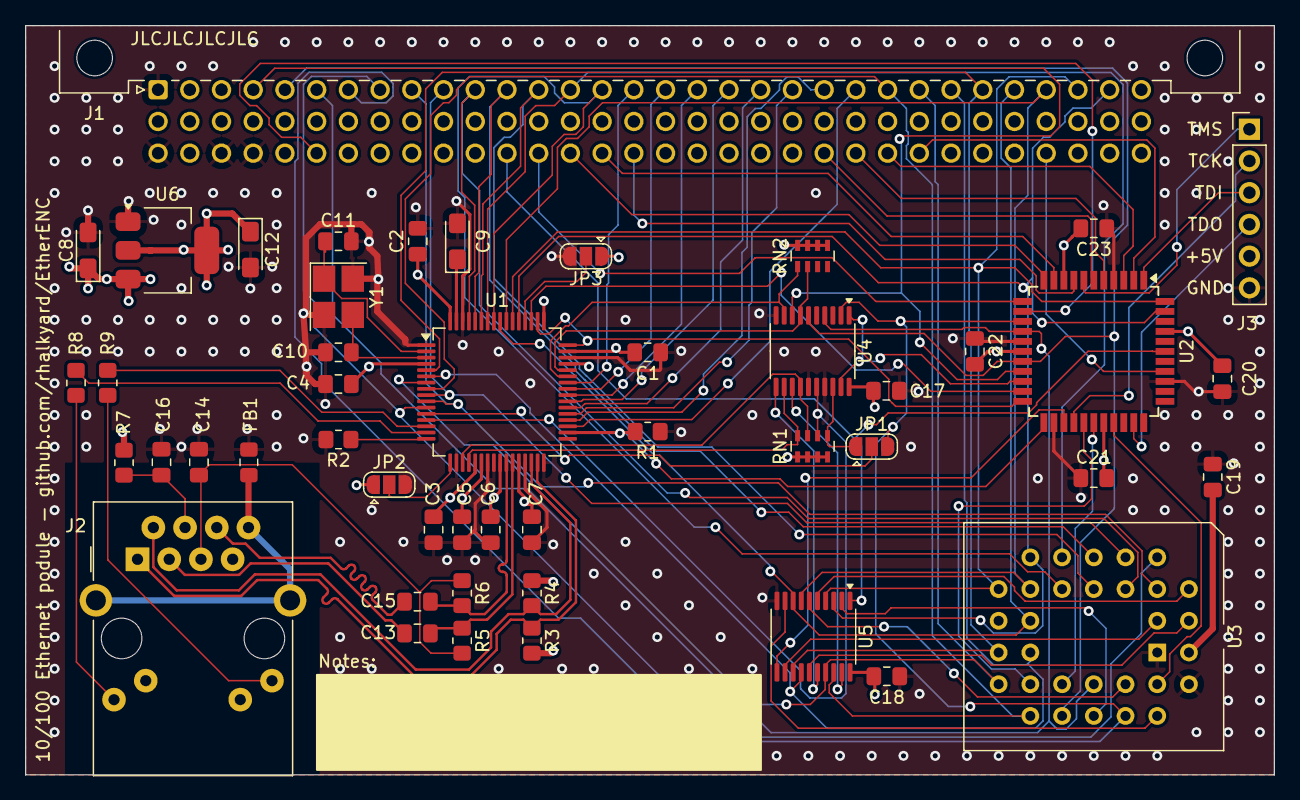
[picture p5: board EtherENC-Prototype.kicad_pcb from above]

Board: 4 copper layers, 100.0 x 60.0 mm, 49 parts (0 on the bottom side), 88 nets.

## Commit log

2025-10-30 Make hardware description match current hardware
2025-11-24 fix mbuf leak when transmitting multiple chains
